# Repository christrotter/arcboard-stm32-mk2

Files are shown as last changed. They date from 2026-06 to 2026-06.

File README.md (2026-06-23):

# arcboard-stm32-mk2
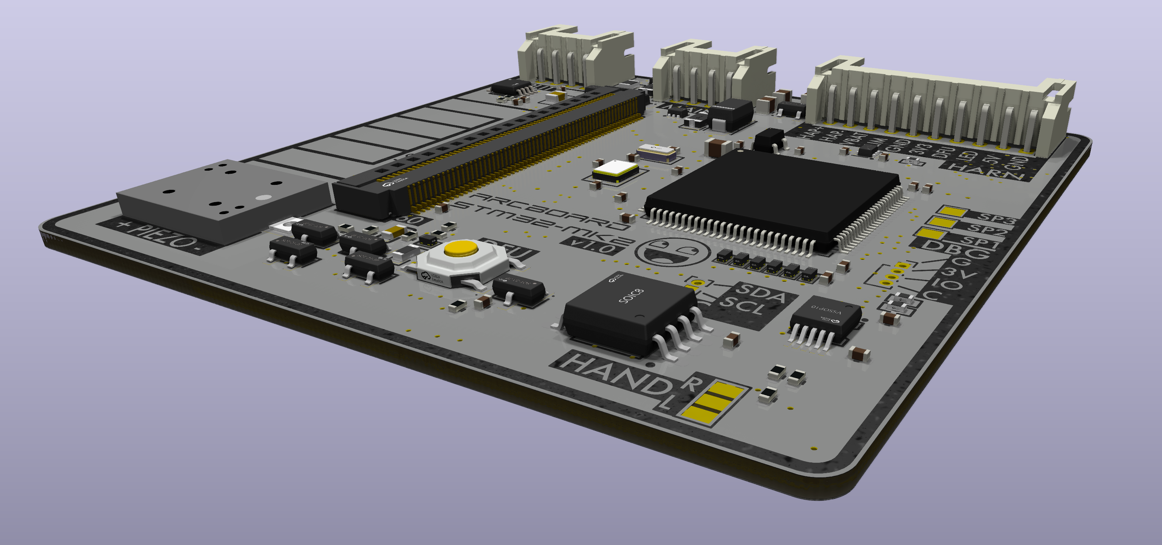
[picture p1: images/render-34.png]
Render

Next iteration of the [STM32F405 mainboard](https://github.com/christrotter/arcboard-stm32).

## Features
- STM32F407 w. 12mHz HSE crystal
- 60x60mm footprint
- **60-pin FFC connector** for [the bespoke FFC loom](https://github.com/christrotter/arcboard-mk22-ffc)
  - Connects: 3x encoders, 4x6 keywell & 5 thumb keys, dpad, 3x paddle buttons, LCD, indicator LED PCBs, PMW3360
- **onboard button** for reset(*momentary*) and boot(*hold*) (*remote output also*)
- 128mb external **flash** via SPI (16MB)
- DRV2605L **haptic** driver via I2C, with PWM trigger (LRA or ERM)
- PAM8302A 2.5w **amplifier & piezo** (*or outputs*)
- 32kHz LSE crystal & **VBAT** wiring (*via external 1.8-3.3v battery*)
- **Two-layer** PCB & PCBA design for more affordable manufacturing
- Both USB connections have **ESD & power protection**
- Designed for **remote-mount** USB ports and boot/reset button
- **Split hand** GPIO via solder jumper
- **VBUS detection** via GPIO
- RGB-5v and LCD-3.3v supplies through MOSFET w. GPIO triggers
- WS2812 signal **level-shifted** to 5v
- Optional outputs
  - I2C
  - Debug
  - Haptic
  - Amplifier out
  - Ground + RGB-5v + WS2812 chain (*continuing from main loom*) for adding more LEDs (*e.g. aesthetic, underglow, etc*)
  - **Limit switch** (pull-up) output

## Improvements
- 100-pin CPU package offers much more flexibility, more options when wiring up the board
- The only soldering required is for JST-PH connectors (*2.0mm pin spacing*)
- Smaller diode package and setup saves space, keeps us on two-layer
- Actually working DFU system this time (*bad LCD pcb caused problems*)
- Fixed a number of issues, including mysterious overheating caused by a poor quality Schottky diode (*and bad spec choice on my part*)
- Inkscape-designed back silkscreen

## QMK notes
- I'm using `ROW2COL` because the Cyboard pcb's are designed this way.

## PCB/PCBA cost
My costs for getting the board made and assembled by JLC, to give you an idea of what this would cost to have built for you.

| Item | Cost (CAD) |
|---|---:|
| Setup fee | $25.56 |
| Stencil | $8.21 |
| Components | $67.86 |
| Extended components fee | $53.55 |
| SMT Assembly | $3.75 |
| Packaging fee | $0.49 |
| Advanced Options | $0.82 |
| Confirm Parts Placement | $0.45 |

## Bill of Materials (BOM)

| Designator | Footprint | Quantity | Value | LCSC Part # |
|---|---|---:|---|---|
| C1, C10, C20, C23 | 0805 | 4 | 4.7uF | C1779 |
| C11, C12, C14, C17, C18, C19, C26, C28, C5, C7, C8, C9 | 0402 | 12 | 100nF | C1525 |
| C13, C15, C2, C24, C27, C4 | 0402 | 6 | 1uF | C52923 |
| C16, C21 | 0402 | 2 | 2.2uF | C12530 |
| C22 | C0603 | 1 | CL10A106MA8NRNC | C96446 |
| C25 | C0805 | 1 | GCM21BR70J106KE22L | C126230 |
| C29, C3, C30, C6 | 0402 | 4 | 12p | C1547 |
| D1 | SMA_L4.3-W2.6-LS5.2-RD | 1 | SS34 | C8678 |
| D10, D11, D2, D3, D6, D8, D9 | X1-DFN1006-2_L1.0-W0.6-RD | 7 | CDSQC4148-HF | C6341459 |
| D4 | SOD-123FL_L2.8-W1.8-LS3.7-BI | 1 | SMF5_0CA_C364279 | C364279 |
| D5, D7 | SOT-666-6_L1.6-W1.2-P0.50-LS1.6-BL | 2 | USBLC6-2P6_C2827693 | C2827693 |
| F2 | F1206 | 1 | 1206L150SLYR | C207037 |
| F3 | F1206 | 1 | MF-NSMF075-2 | C89653 |
| L1 | L0805 | 1 | MPZ2012S101AT000 | C15957 |
| LED-LVL1 | SOT-563_L1.6-W1.2-P0.50-LS1.6-BR | 1 | SN74LVC1T45DRL | C352970 |
| MOSFET1, MOSFET3, MOSFET4 | SOT-23_L2.9-W1.3-P1.90-LS2.4-BR | 3 | AO3401A | C15127 |
| R1 | 0402 | 1 | 0402WGF1004TCE | C26083 |
| R10 | 0402 | 1 | 5.1k | C25905 |
| R11, R12, R16, R17, R2, R3, R5 | 0402 | 7 | 10k | C25744 |
| R4, R7, R8 | R0402 | 3 | 0402WGF4701TCE | C25900 |
| R14 | 0402 | 1 | 0402WGF1000TCE | C25076 |
| R15 | 0402 | 1 | 0402WGF1001TCE | C11702 |
| R6 | R0603 | 1 | 0603WAF3303T5E | C23137 |
| R9 | 0402 | 1 | 0402WGF1003TCE | C25741 |
| U1 | SOT-23-5 | 1 | XC6210B332MR-G | C82942 |
| U10, U9 | SOT-23-3_L2.9-W1.3-P1.90-LS2.4-BR | 2 | MMUN2233LT1G | C86932 |
| U13, U4 | SOT-23-3_L2.9-W1.3-P1.90-LS2.4-BR | 2 | 2N7002 | C8545 |
| U14 | SOIC-8_L5.3-W5.3-P1.27-LS8.0-BL | 1 | W25Q128JVSIQTR | C97521 |
| U15 | SW-SMD_4P-L5.1-W5.1-P3.70-LS6.5-TL_H1.5 | 1 | TS-1187A-B-A-B | C318884 |
| U2 | LQFP-100_14x14mm_P0.5mm | 1 | STM32F407VGTx | C12345 |
| U3 | FPC-SMD_FH52-60S-0.5SH | 1 | FH52-60S-0_5SH | C224193 |
| U5 | VSSOP-10_L3.0-W3.0-P0.50-LS4.9-BL | 1 | DRV2605LDGSR | C527464 |
| U6 | MSOP-8_L3.0-W3.0-P0.65-LS5.0-BL | 1 | PAM8302AASCR | C113367 |
| U8 | OSC-SMD_L3.2-W1.5 | 1 | SC-32S32_768kHz20PPM7pF | C97604 |
| Y1 | CRYSTAL-SMD_4P-L3.2-W2.5-BL-1 | 1 | Crystal_GND24 | C9002 |

Total line items: 35  
Total component quantity: 77

## Renders

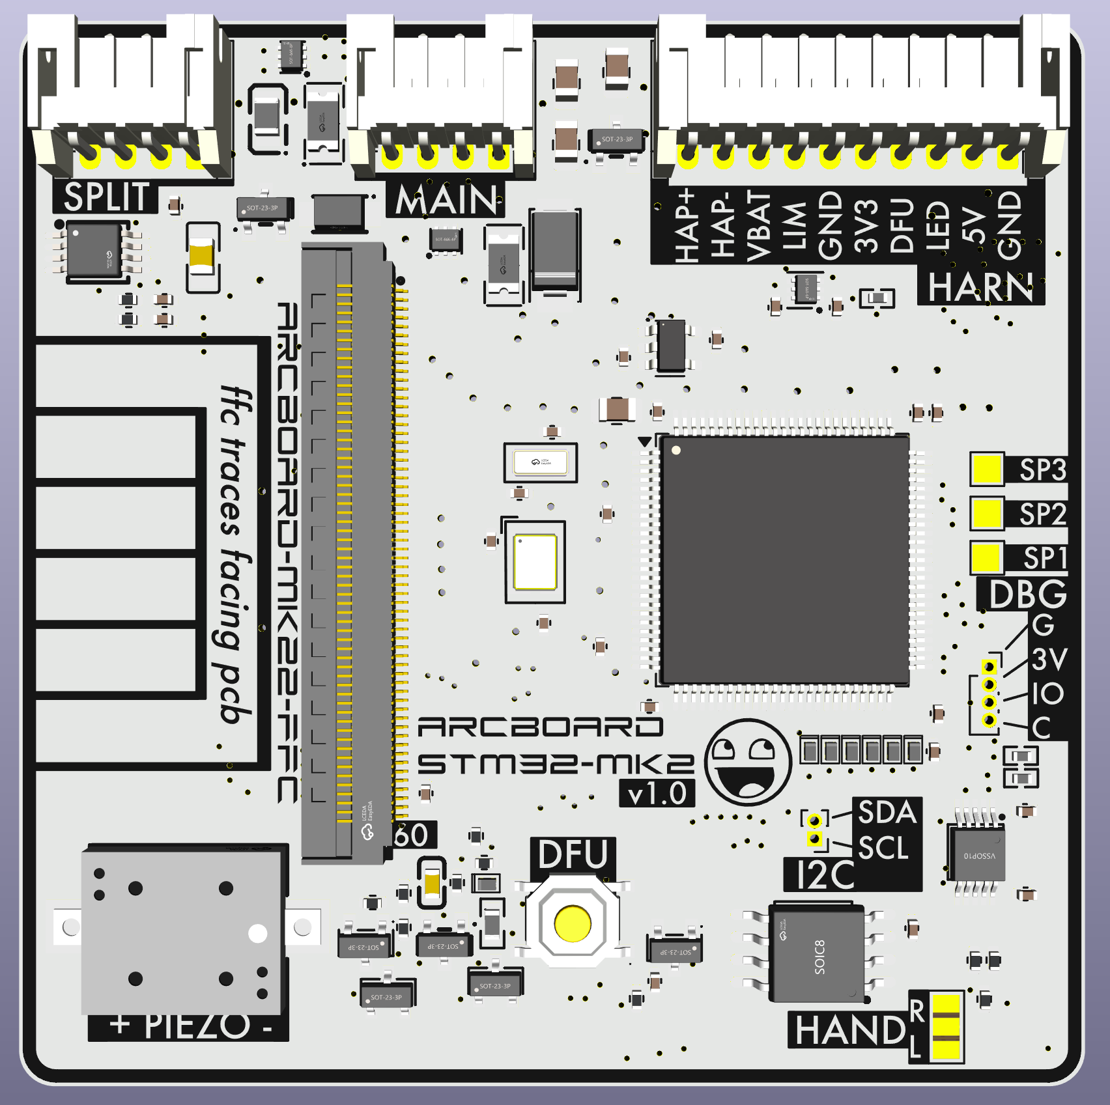
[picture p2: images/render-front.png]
Render


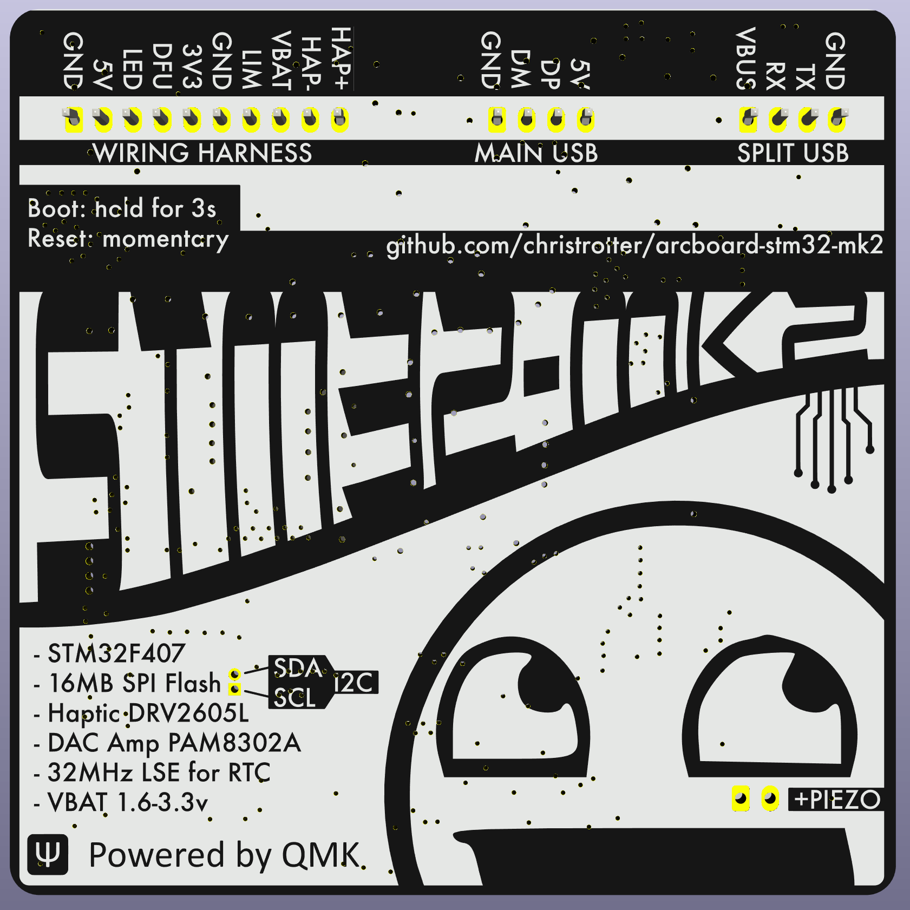
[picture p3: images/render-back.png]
Render


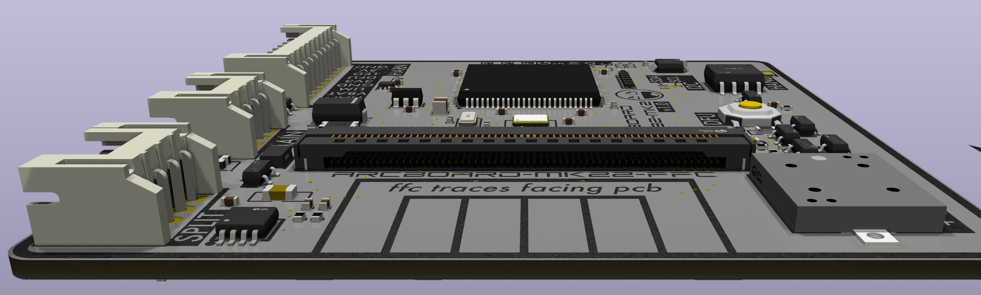
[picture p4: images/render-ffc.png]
Render


## PCB layout
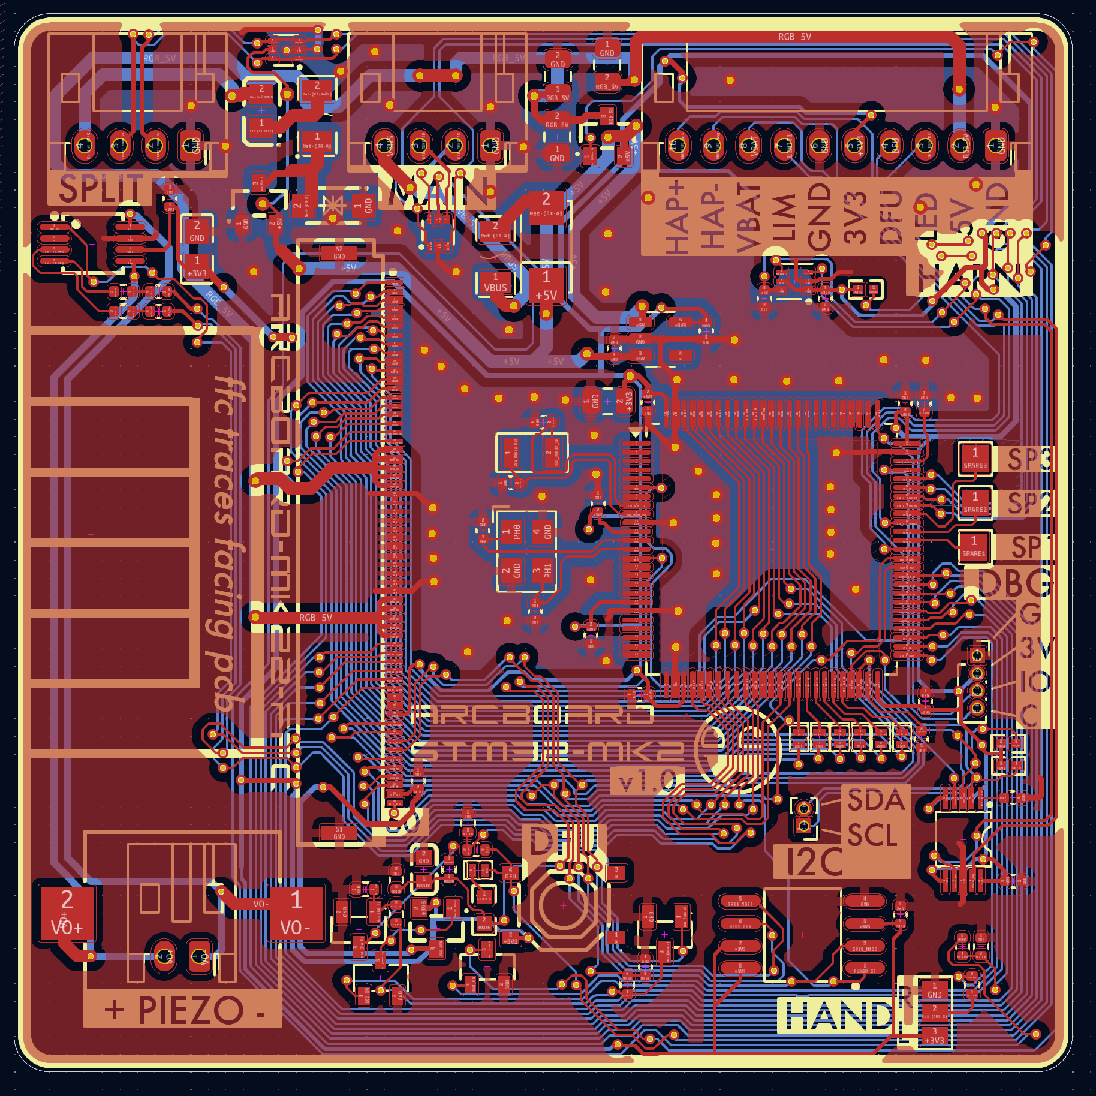
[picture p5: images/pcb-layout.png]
PCB Layout


## Schematic
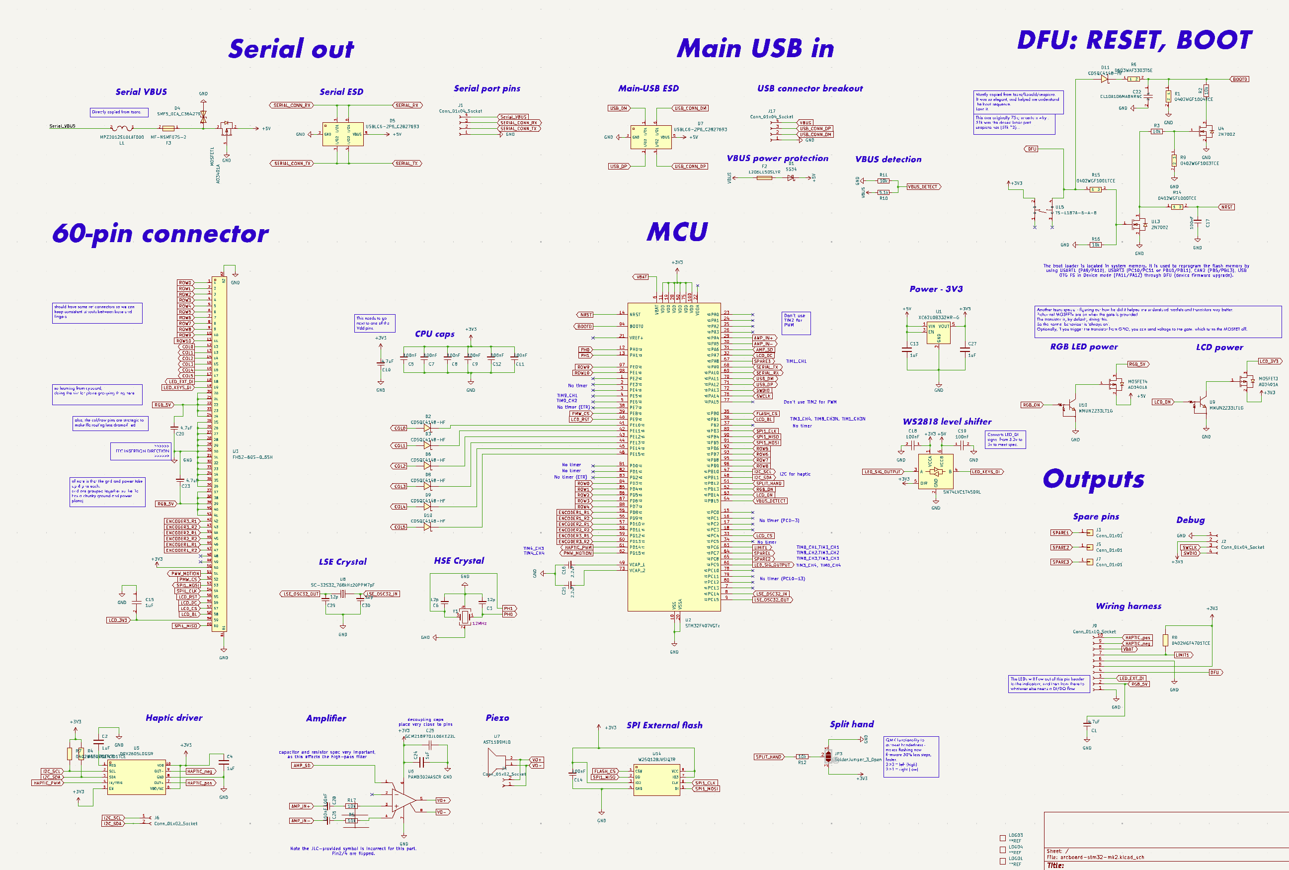
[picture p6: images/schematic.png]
Schematic


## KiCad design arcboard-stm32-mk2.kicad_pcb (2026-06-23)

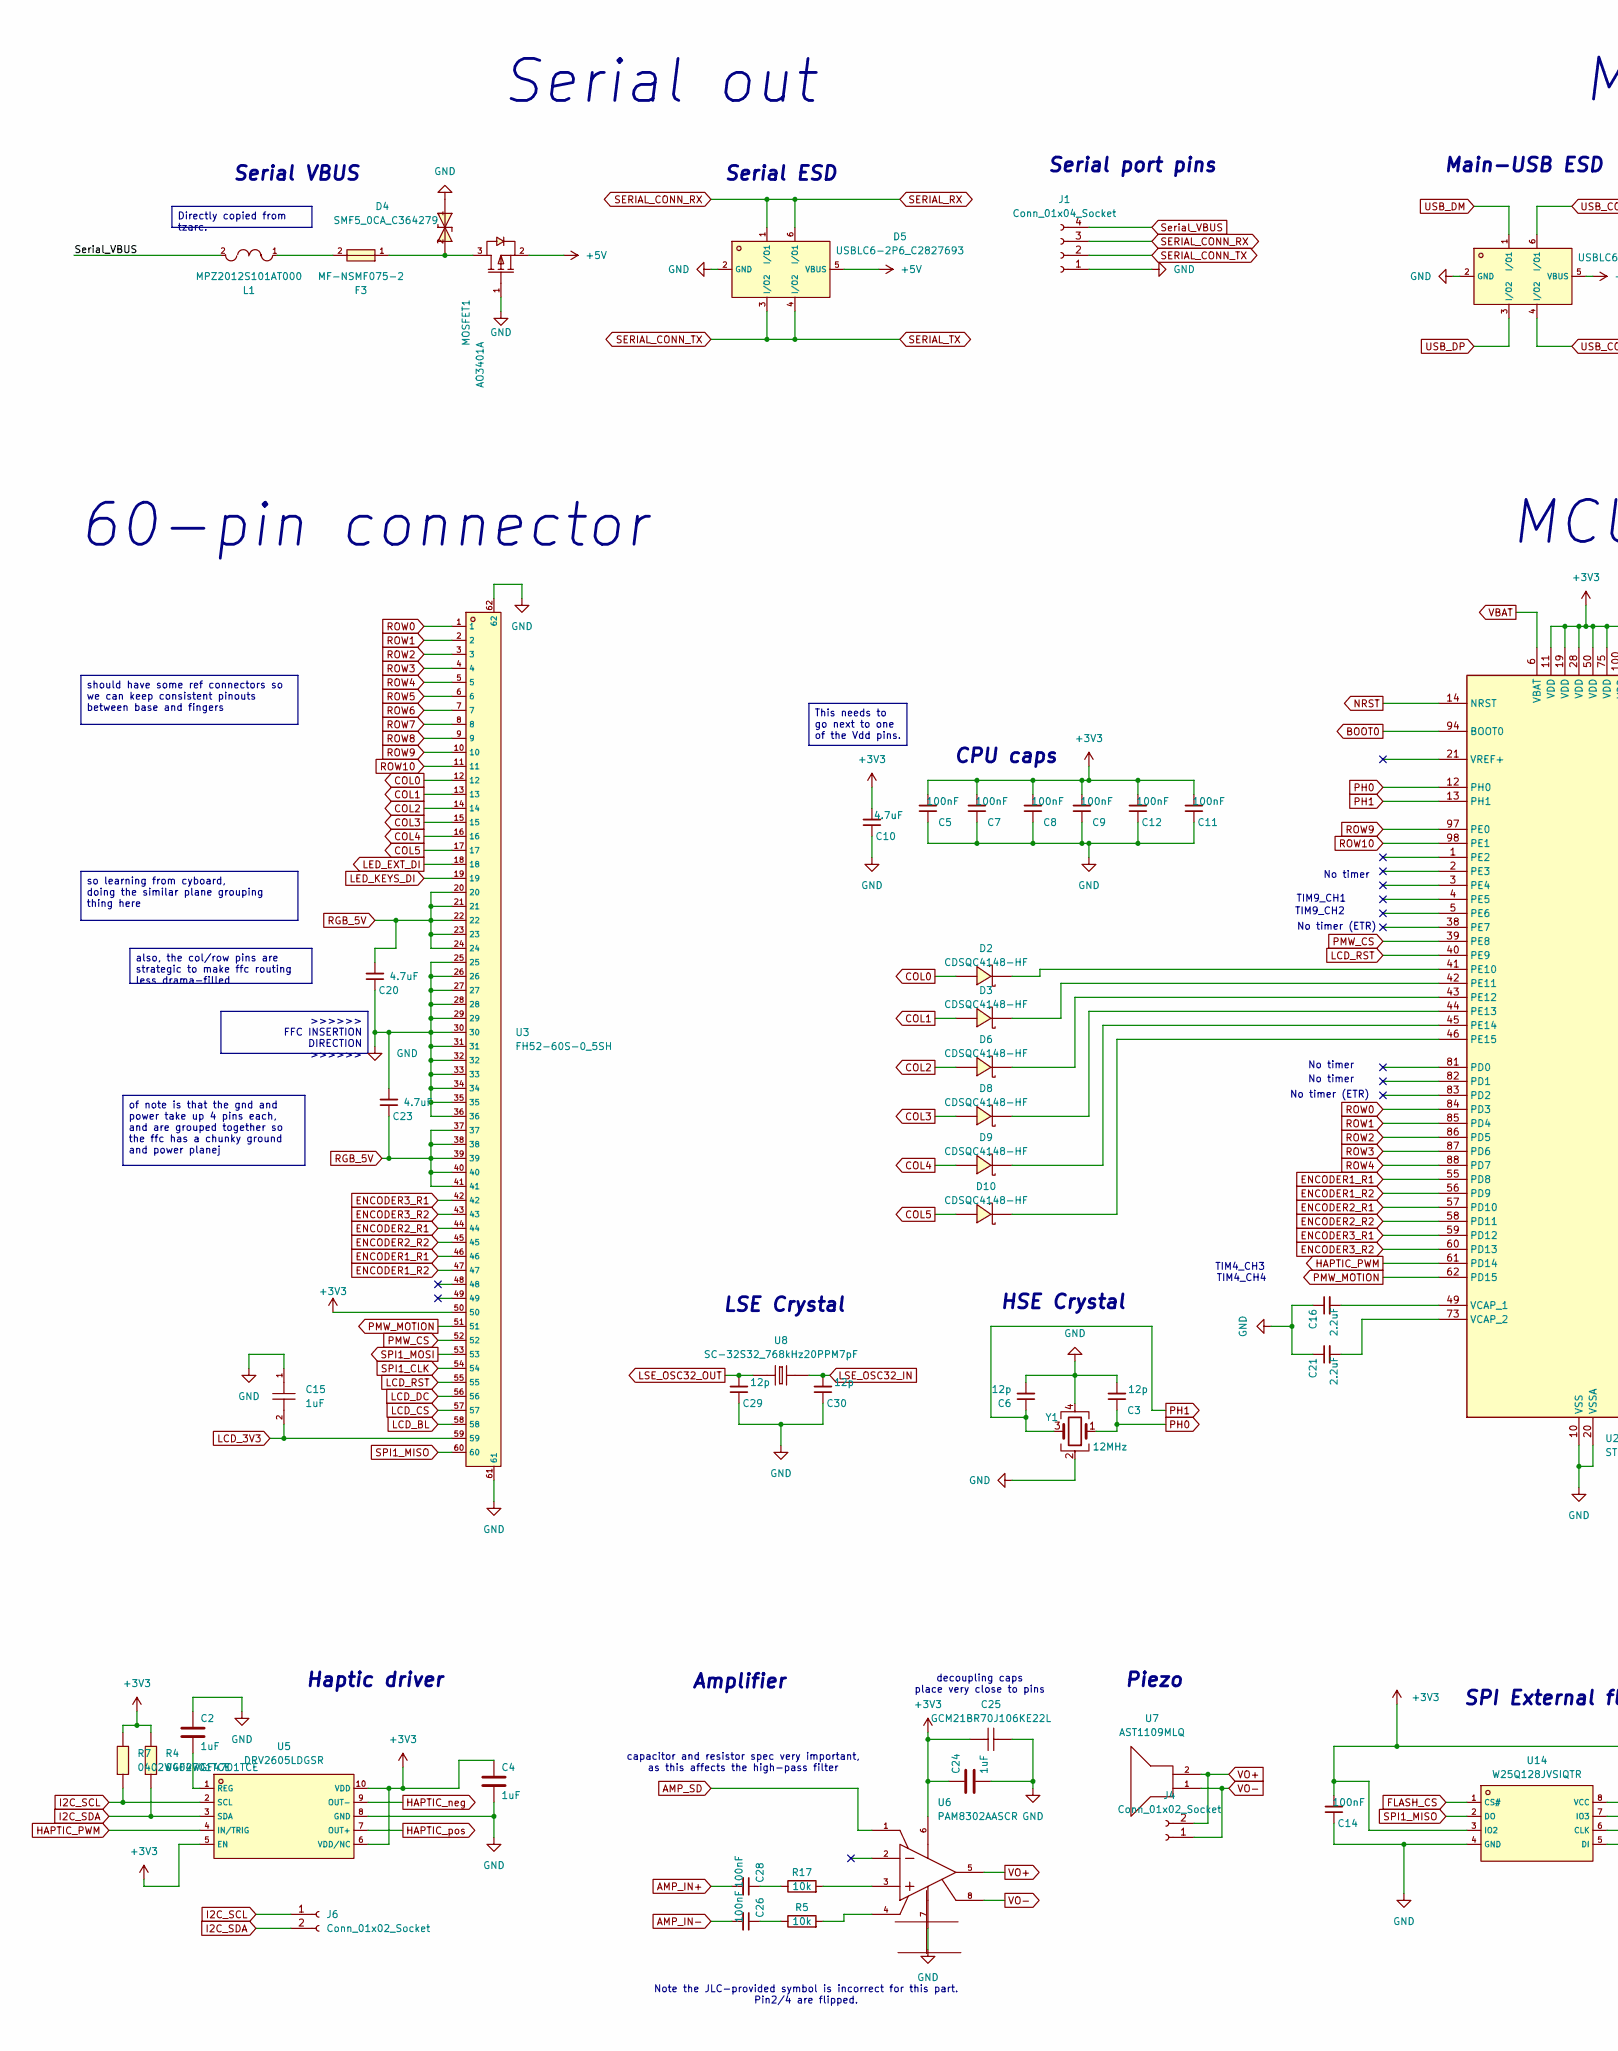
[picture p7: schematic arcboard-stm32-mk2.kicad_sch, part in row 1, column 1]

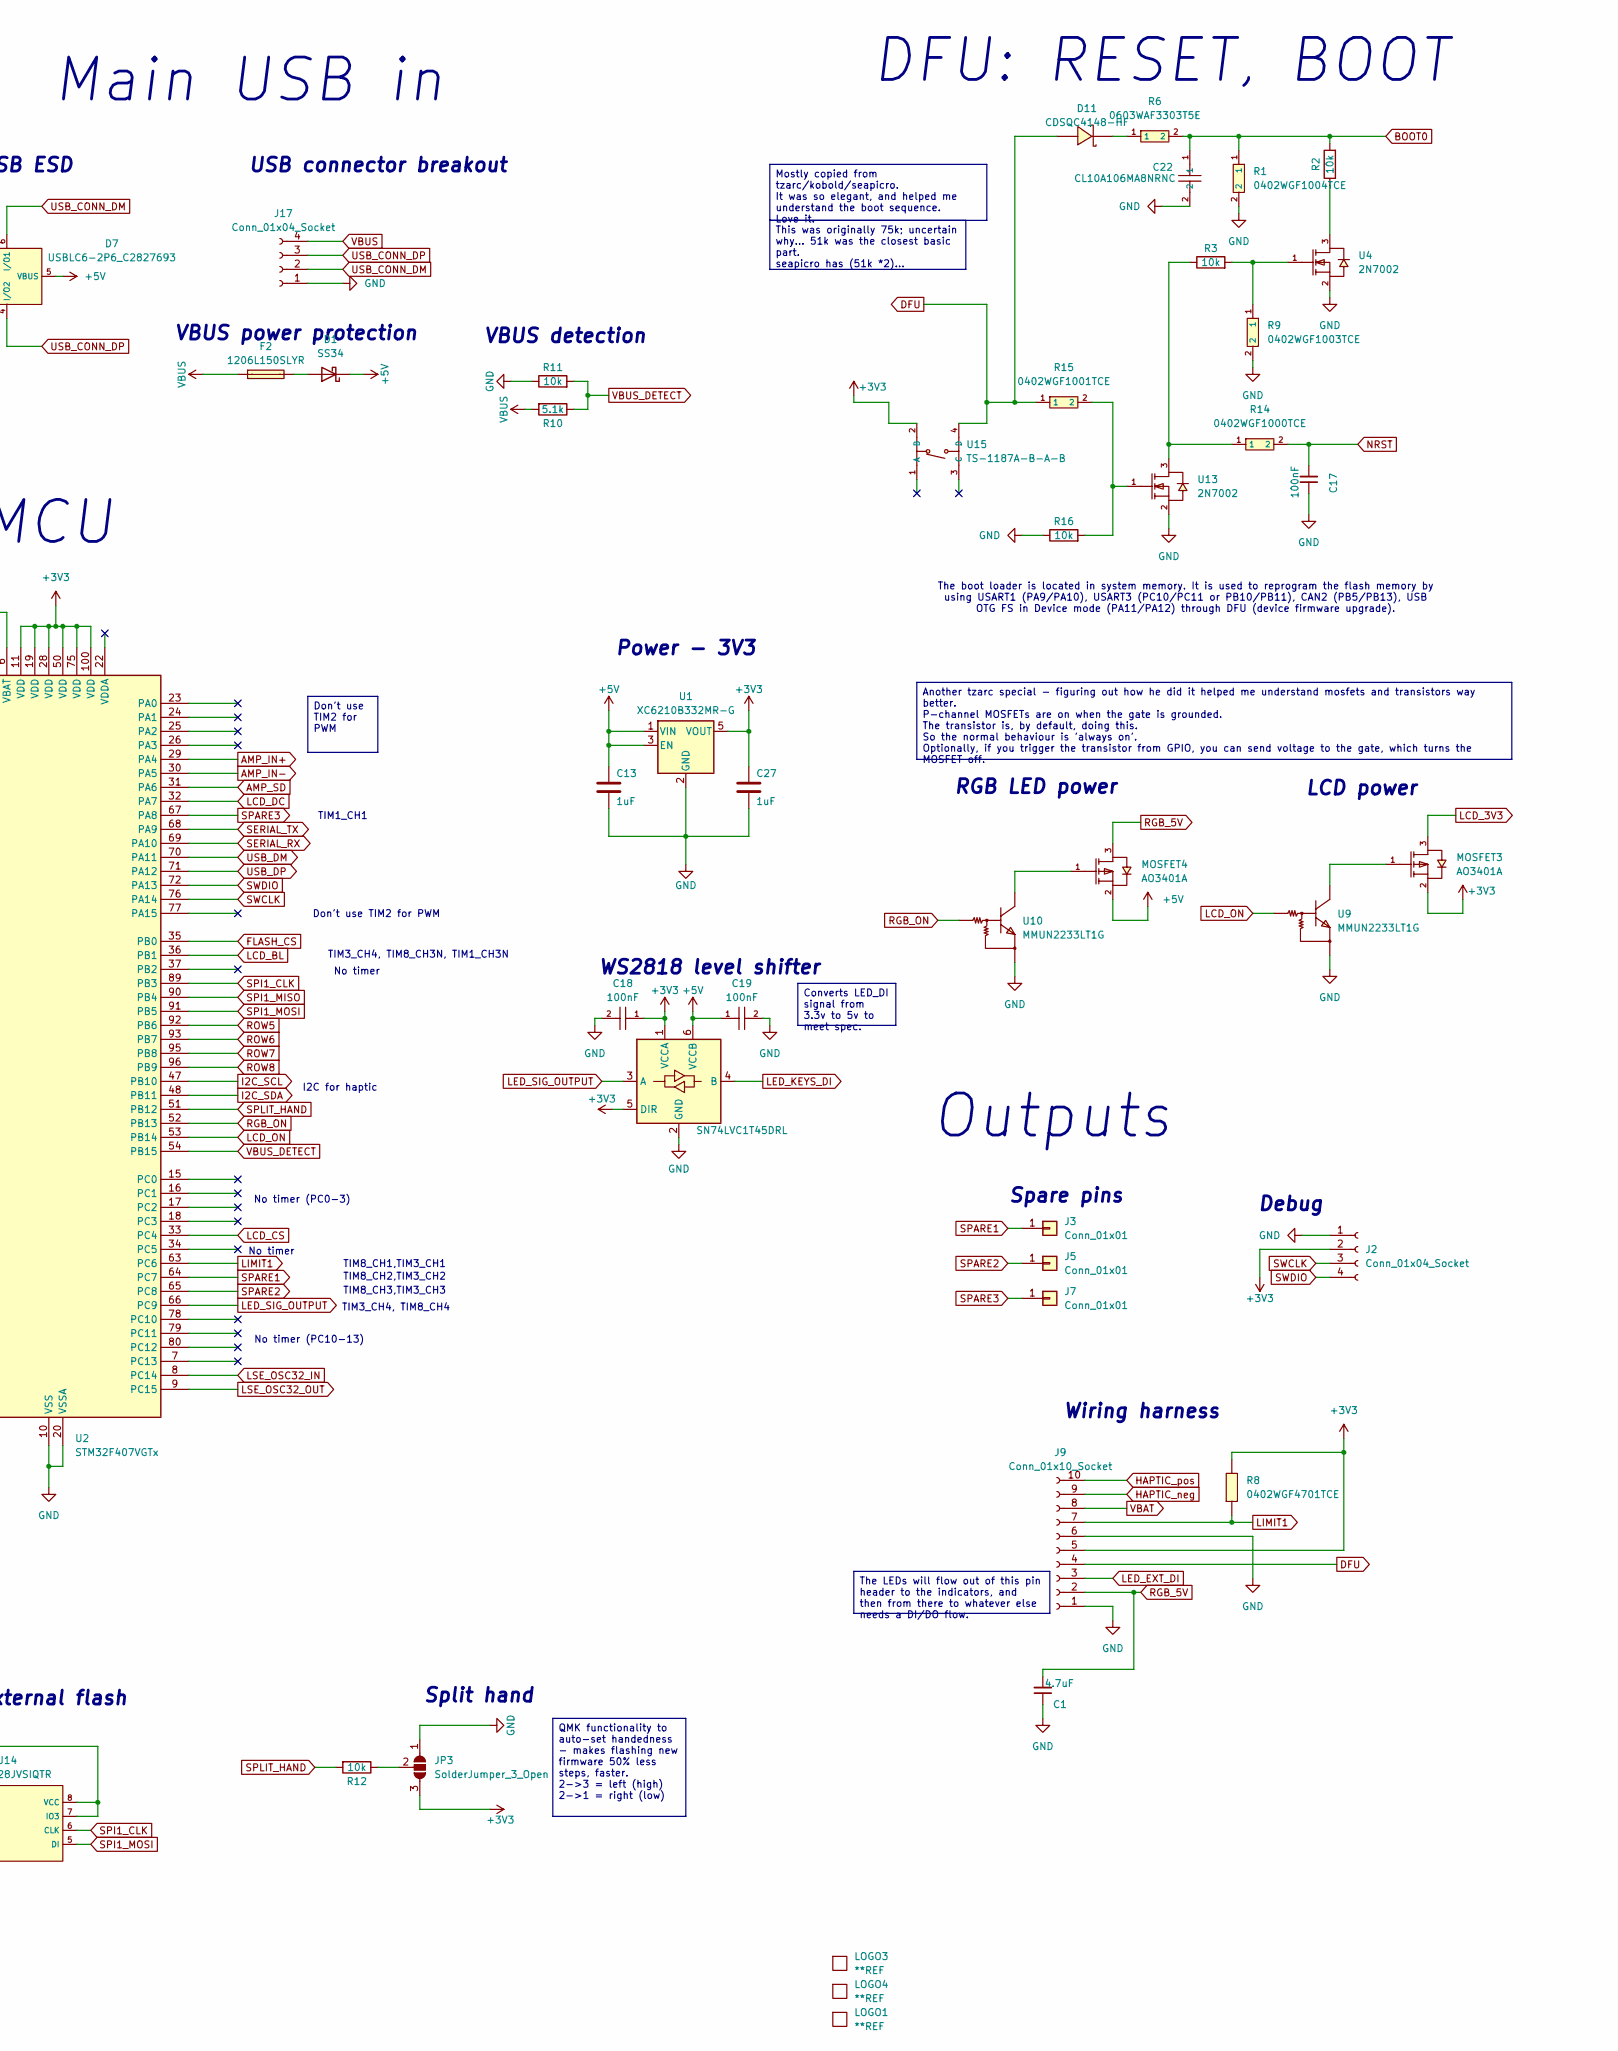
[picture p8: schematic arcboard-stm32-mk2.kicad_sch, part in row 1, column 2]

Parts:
C1, C10, C20, C23: 4.7uF; C_0805_2012Metric; LCSC C1779
C2, C4, C13, C15, C24, C27: 1uF; C_0402_1005Metric; LCSC C52923
C3, C6, C29, C30: 12p; C_0402_1005Metric; LCSC C1547
C5, C7, C8, C9, C11, C12, C14, C17, C18, C19, C26, C28: 100nF; C_0402_1005Metric; LCSC C1525
C16, C21: 2.2uF; C_0402_1005Metric; LCSC C12530
C22: CL10A106MA8NRNC; C0603; LCSC C96446
C25: GCM21BR70J106KE22L; C0805; LCSC C126230
D1: SS34; SMA_L4.3-W2.6-LS5.2-RD; LCSC C8678
D2, D3, D6, D8, D9, D10, D11: CDSQC4148-HF; X1-DFN1006-2_L1.0-W0.6-RD; LCSC C6341459
D4: SMF5_0CA_C364279; SOD-123FL_L2.8-W1.8-LS3.7-BI; LCSC C364279
D5, D7: USBLC6-2P6_C2827693; SOT-666-6_L1.6-W1.2-P0.50-LS1.6-BL; LCSC C2827693
F2: 1206L150SLYR; F1206; LCSC C207037
F3: MF-NSMF075-2; F1206; LCSC C89653
J1, J17: Conn_01x04_Socket; JST_PH_S4B-PH-K_1x04_P2.00mm_Horizontal
J2: Conn_01x04_Socket; PinSocket_1x04_P1.00mm_Vertical
J3, J5, J7: Conn_01x01; TestPoint_Pad_1.5x1.5mm
J4: Conn_01x02_Socket; JST_PH_S2B-PH-K_1x02_P2.00mm_Horizontal
J6: Conn_01x02_Socket; PinHeader_1x02_P1.00mm_Vertical
J9: Conn_01x10_Socket; JST_PH_S10B-PH-K_1x10_P2.00mm_Horizontal
JP3: SolderJumper_3_Open; SolderJumper-3_P1.3mm_Open_Pad1.0x1.5mm
L1: MPZ2012S101AT000; L0805; LCSC C15957
LED-LVL1: SN74LVC1T45DRL; SOT-563_L1.6-W1.2-P0.50-LS1.6-BR; MPN SN74LVC1T45DRLR; JLC Basic N
LOGO1: **REF; awesome-logo
LOGO3: **REF; cyboard-logo-10mm
LOGO4: **REF; qmk-lite
MOSFET1, MOSFET3, MOSFET4: AO3401A; SOT-23_L2.9-W1.3-P1.90-LS2.4-BR; LCSC C15127
R1: 0402WGF1004TCE; R_0402_1005Metric; LCSC C26083
R2, R3, R5, R11, R12, R16, R17: 10k; R_0402_1005Metric; LCSC C25744
R4, R7, R8: 0402WGF4701TCE; R0402; LCSC C25900
R6: 0603WAF3303T5E; R0603; LCSC C23137
R9: 0402WGF1003TCE; R_0402_1005Metric; LCSC C25741
R10: 5.1k; R_0402_1005Metric; LCSC C25905
R14: 0402WGF1000TCE; R_0402_1005Metric; LCSC C25076
R15: 0402WGF1001TCE; R_0402_1005Metric; LCSC C11702
U1: XC6210B332MR-G; SOT-23-5; LCSC C82942
U2: STM32F407VGTx; LQFP-100_14x14mm_P0.5mm; LCSC C12345
U3: FH52-60S-0_5SH; FPC-SMD_FH52-60S-0.5SH; LCSC C224193
U4, U13: 2N7002; SOT-23-3_L2.9-W1.3-P1.90-LS2.4-BR; LCSC C8545
U5: DRV2605LDGSR; VSSOP-10_L3.0-W3.0-P0.50-LS4.9-BL; LCSC C527464
U6: PAM8302AASCR; MSOP-8_L3.0-W3.0-P0.65-LS5.0-BL; LCSC C113367
U7: AST1109MLQ; BUZ-SMD_L11.0-W9.0; LCSC C9900020429
U8: SC-32S32_768kHz20PPM7pF; OSC-SMD_L3.2-W1.5; LCSC C97604
U9, U10: MMUN2233LT1G; SOT-23-3_L2.9-W1.3-P1.90-LS2.4-BR; LCSC C86932
U14: W25Q128JVSIQTR; SOIC-8_L5.3-W5.3-P1.27-LS8.0-BL; LCSC C97521
U15: TS-1187A-B-A-B; SW-SMD_4P-L5.1-W5.1-P3.70-LS6.5-TL_H1.5; LCSC C318884
Y1: Crystal_GND24; CRYSTAL-SMD_4P-L3.2-W2.5-BL-1; LCSC C9002

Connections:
+3V3: C4.1, C5.2, C7.2, C8.2, C9.2, C10.2, C11.2, C12.2, C14.2, C18.1, C24.1, C25.1, C27.1, J2.2, J9.5, JP3.3 (B), LED-LVL1.1 (VCCA), LED-LVL1.5 (DIR), MOSFET3.2 (S), R4.2, R7.2, R8.2, U1.5 (VOUT), U2.11 (VDD), U2.19 (VDD), U2.28 (VDD), U2.50 (VDD), U2.75 (VDD), U2.100 (VDD), U3.50, U5.5 (EN), U5.6 (VDD/NC), U5.10 (VDD), U6.6 (VDD), U14.3 (IO2), U14.7 (IO3), U14.8 (VCC), U15.2 (B)
+5V: C13.1, C19.1, D1.1 (K), D5.5 (VBUS), D7.5 (VBUS), LED-LVL1.6 (VCCB), MOSFET1.2 (S), MOSFET4.2 (S), U1.1 (VIN), U1.3 (EN)
AMP_IN+: C28.2, U2.29 (PA4)
AMP_IN-: C26.2, U2.30 (PA5)
AMP_SD: U2.31 (PA6), U6.1 (SD#)
BOOT0: C22.1, R1.1, R2.2, R6.2, U2.94 (BOOT0)
COL0: D2.2 (A), U3.12
COL1: D3.2 (A), U3.13
COL2: D6.2 (A), U3.14
COL3: D8.2 (A), U3.15
COL4: D9.2 (A), U3.16
COL5: D10.2 (A), U3.17
DFU: D11.2 (A), J9.4, R15.1, U15.4 (D)
ENCODER1_R1: U2.55 (PD8), U3.46
ENCODER1_R2: U2.56 (PD9), U3.47
ENCODER2_R1: U2.57 (PD10), U3.44
ENCODER2_R2: U2.58 (PD11), U3.45
ENCODER3_R1: U2.59 (PD12), U3.42
ENCODER3_R2: U2.60 (PD13), U3.43
FLASH_CS: U2.35 (PB0), U14.1 (CS#)
GND: C1.1, C2.1, C3.2, C4.2, C5.1, C6.2, C7.1, C8.1, C9.1, C10.1, C11.1, C12.1, C13.2, C14.1, C15.1, C16.1, C17.1, C18.2, C19.2, C20.1, C21.1, C22.2, C23.2, C24.2, C25.2, C27.2, C29.1, C30.1, D4.1 (K), D5.2 (GND), D7.2 (GND), J1.1, J2.1, J9.1, J9.6, J17.1, JP3.1 (A), LED-LVL1.2 (GND), MOSFET1.1 (G), R1.2, R9.2, R11.1, R16.1, U1.2 (GND), U2.10 (VSS), U2.20 (VSSA), U2.27 (VSS), U2.74 (VSS), U2.99 (VSS), U3.25, U3.26, U3.27, U3.28, U3.29, U3.30, U3.31, U3.32, U3.33, U3.34, U3.35, U3.36, U3.61, U3.62, U4.2 (S), U5.8 (GND), U6.7 (GND), U9.2 (E), U10.2 (E), U13.2 (S), U14.4 (GND), Y1.2, Y1.4
HAPTIC_PWM: U2.61 (PD14), U5.4 (IN/TRIG)
HAPTIC_neg: J9.9, U5.9 (OUT-)
HAPTIC_pos: J9.10, U5.7 (OUT+)
I2C_SCL: J6.1, R7.1, U2.47 (PB10), U5.2 (SCL)
I2C_SDA: J6.2, R4.1, U2.48 (PB11), U5.3 (SDA)
LCD_3V3: C15.2, MOSFET3.3 (D), U3.59
LCD_BL: U2.36 (PB1), U3.58
LCD_CS: U2.33 (PC4), U3.57
LCD_DC: U2.32 (PA7), U3.56
LCD_ON: U2.53 (PB14), U9.1 (B)
LCD_RST: U2.40 (PE9), U3.55
LED_EXT_DI: J9.3, U3.18
LED_KEYS_DI: LED-LVL1.4 (B), U3.19
LED_SIG_OUTPUT: LED-LVL1.3 (A), U2.66 (PC9)
LIMIT1: J9.7, R8.1, U2.63 (PC6)
LSE_OSC32_IN: C30.2, U2.8 (PC14), U8.2
LSE_OSC32_OUT: C29.2, U2.9 (PC15), U8.1
NRST: C17.2, R14.2, U2.14 (NRST)
unnamed: C26.1, R5.1
unnamed: C28.1, R17.1
unnamed: D1.2 (A), F2.2
unnamed: D2.1 (K), U2.41 (PE10)
unnamed: D3.1 (K), U2.42 (PE11)
unnamed: D4.2 (A), F3.1, MOSFET1.3 (D)
unnamed: D6.1 (K), U2.43 (PE12)
unnamed: D8.1 (K), U2.44 (PE13)
unnamed: D9.1 (K), U2.45 (PE14)
unnamed: D10.1 (K), U2.46 (PE15)
unnamed: D11.1 (K), R6.1
unnamed: F3.2, L1.1
unnamed: JP3.2 (C), R12.1
unnamed: MOSFET3.1 (G), U9.3 (C)
unnamed: MOSFET4.1 (G), U10.3 (C)
unnamed: C16.2, U2.49 (VCAP_1)
unnamed: C21.2, U2.73 (VCAP_2)
unnamed: R2.1, U4.3 (D)
unnamed: R3.2, R9.1, U4.1 (G)
unnamed: C2.2, U5.1 (REG)
unnamed: R17.2, U6.3 (IN+)
unnamed: R5.2, U6.4 (IN-)
unnamed: R3.1, R14.1, U13.3 (D)
unnamed: R15.2, R16.2, U13.1 (G)
PH0: C3.1, U2.12 (PH0), Y1.1
PH1: C6.1, U2.13 (PH1), Y1.3
PMW_CS: U2.39 (PE8), U3.52
PMW_MOTION: U2.62 (PD15), U3.51
RGB_5V: C1.2, C20.2, C23.1, J9.2, MOSFET4.3 (D), U3.20, U3.21, U3.22, U3.23, U3.24, U3.37, U3.38, U3.39, U3.40, U3.41
RGB_ON: U2.52 (PB13), U10.1 (B)
ROW0: U2.84 (PD3), U3.1
ROW1: U2.85 (PD4), U3.2
ROW2: U2.86 (PD5), U3.3
ROW3: U2.87 (PD6), U3.4
ROW4: U2.88 (PD7), U3.5
ROW5: U2.92 (PB6), U3.6
ROW6: U2.93 (PB7), U3.7
ROW7: U2.95 (PB8), U3.8
ROW8: U2.96 (PB9), U3.9
ROW9: U2.97 (PE0), U3.10
ROW10: U2.98 (PE1), U3.11
SERIAL_CONN_RX: D5.1 (I/O1), D5.6 (I/O1), J1.3, U2.69 (PA10)
SERIAL_CONN_TX: D5.3 (I/O2), D5.4 (I/O2), J1.2, U2.68 (PA9)
SPARE1: J3.1, U2.64 (PC7)
SPARE2: J5.1, U2.65 (PC8)
SPARE3: J7.1, U2.67 (PA8)
SPI1_CLK: U2.89 (PB3), U3.54, U14.6 (CLK)
SPI1_MISO: U2.90 (PB4), U3.60, U14.2 (DO)
SPI1_MOSI: U2.91 (PB5), U3.53, U14.5 (DI)
SPLIT_HAND: R12.2, U2.51 (PB12)
SWCLK: J2.3, U2.76 (PA14)
SWDIO: J2.4, U2.72 (PA13)
Serial_VBUS: J1.4, L1.2
USB_CONN_DM: D7.6 (I/O1), J17.2
USB_CONN_DP: D7.4 (I/O2), J17.3
USB_DM: D7.1 (I/O1), U2.70 (PA11)
USB_DP: D7.3 (I/O2), U2.71 (PA12)
VBAT: J9.8, U2.6 (VBAT)
VBUS: F2.1, J17.4, R10.2
VBUS_DETECT: R10.1, R11.2, U2.54 (PB15)
VO+: J4.2, U6.5 (VO+), U7.2
VO-: J4.1, U6.8 (VO-), U7.1

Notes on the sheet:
No timer (PC10-13)
Amplifier
LSE Crystal
TIM9_CH2
DFU: RESET, BOOT
TIM8_CH3,TIM3_CH3
Serial VBUS
I2C for haptic
No timer
TIM3_CH4, TIM8_CH4
TIM8_CH2,TIM3_CH2
Serial port pins
Outputs
USB connector breakout
Don't use TIM2 for PWM
No timer (ETR)
TIM1_CH1
decoupling caps place very close to pins
HSE Crystal
Main USB in
TIM8_CH1,TIM3_CH1
CPU caps
No timer (PC0-3)
VBUS detection
RGB LED power
Wiring harness
SPI External flash
Piezo
Power - 3V3
TIM9_CH1
TIM3_CH4, TIM8_CH3N, TIM1_CH3N
Note the JLC-provided symbol is incorrect for this part. Pin2/4 are flipped.
LCD power
Spare pins
60-pin connector
WS2818 level shifter
Split hand
Haptic driver
capacitor and resistor spec very important, as this affects the high-pass filter
TIM4_CH4

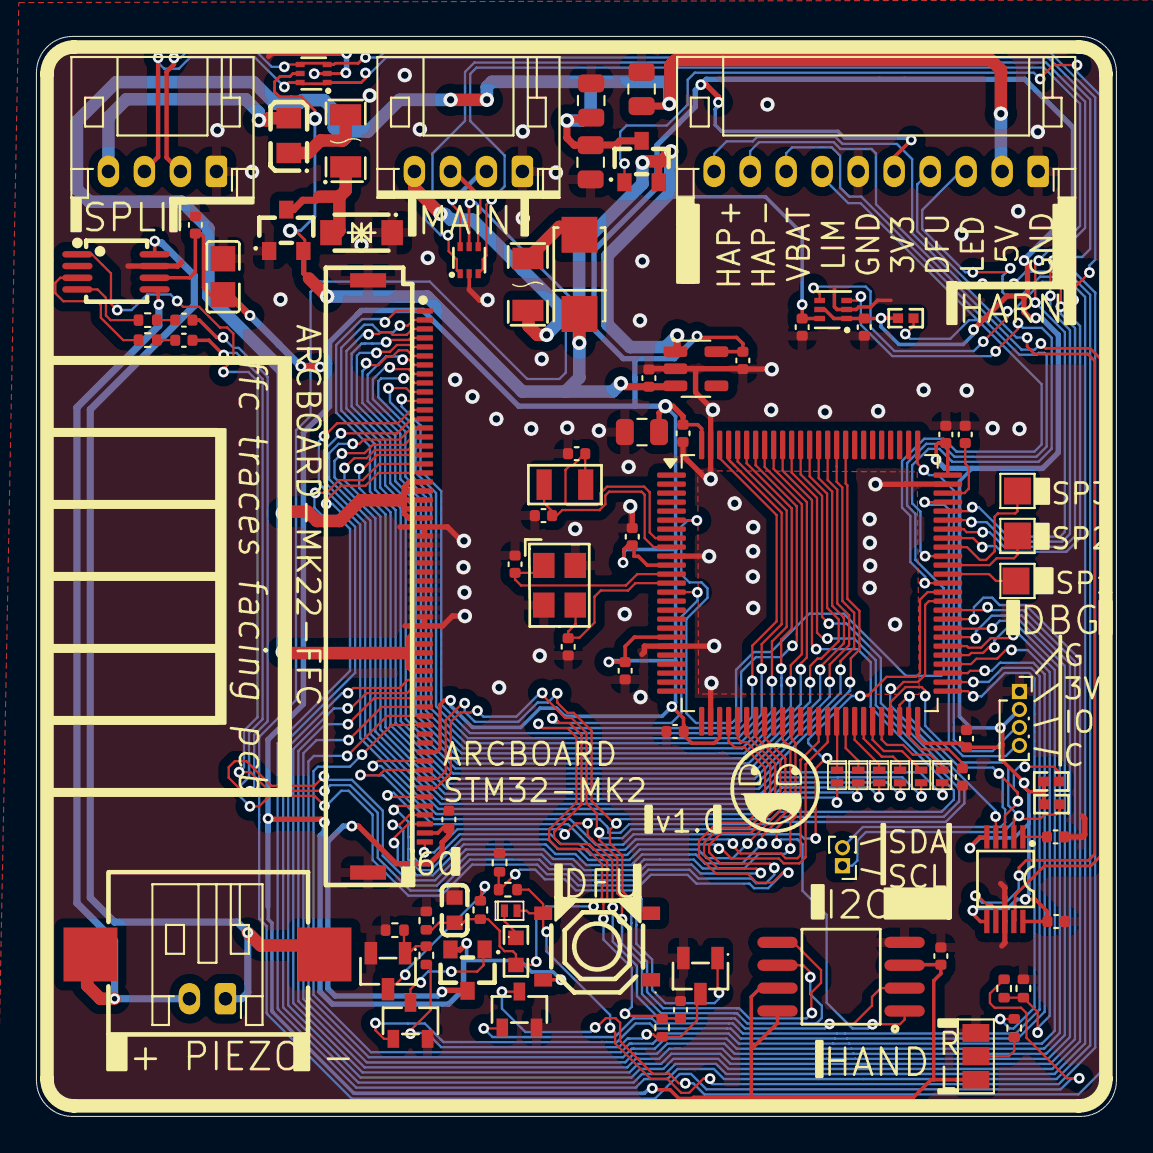
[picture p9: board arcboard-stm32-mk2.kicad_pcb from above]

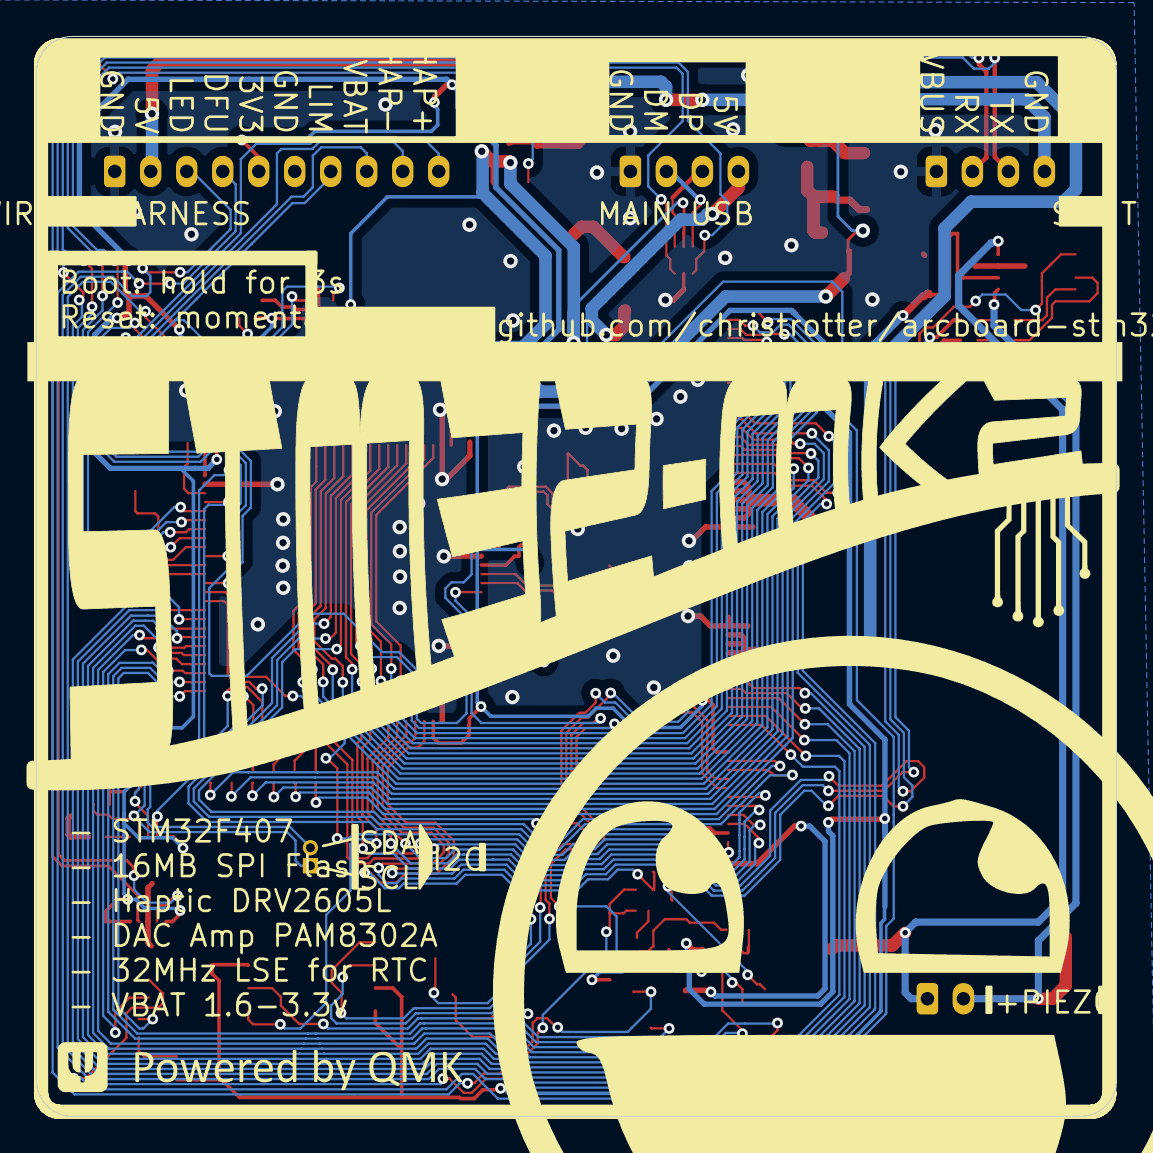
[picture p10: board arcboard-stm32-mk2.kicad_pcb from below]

Board: 2 copper layers, 60.0 x 60.0 mm, 91 parts (2 on the bottom side), 101 nets.

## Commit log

2026-05-31 adding first draft kicad files
    [arcboard-stm32-mk2.kicad_pcb, arcboard-stm32-mk2.kicad_sch]
2026-06-01 starting readme, added haptic
    [arcboard-stm32-mk2.kicad_pcb, arcboard-stm32-mk2.kicad_sch]
2026-06-01 finishing haptic bits
    [arcboard-stm32-mk2.kicad_pcb, arcboard-stm32-mk2.kicad_sch]
2026-06-01 adding dac amp
    [arcboard-stm32-mk2.kicad_pcb, arcboard-stm32-mk2.kicad_sch]
2026-06-02 adding piezo that does not fit
    [arcboard-stm32-mk2.kicad_pcb, arcboard-stm32-mk2.kicad_sch]
2026-06-02 re-organized the bottom section to fit a piezo
    [arcboard-stm32-mk2.kicad_pcb, arcboard-stm32-mk2.kicad_sch]
2026-06-03 silkscreen work, adding lse crystal and vbat hookup
    [arcboard-stm32-mk2.kicad_pcb, arcboard-stm32-mk2.kicad_sch]
2026-06-04 fixing issues brought up by drashna, adding timer notation to schematic
    [arcboard-stm32-mk2.kicad_pcb, arcboard-stm32-mk2.kicad_sch]
2026-06-04 improving top silkscreen
    [arcboard-stm32-mk2.kicad_pcb]
2026-06-04 top silkscreen good enough for now
    [arcboard-stm32-mk2.kicad_pcb]
2026-06-05 silkscreen mostly done, fixed some DRC issues
    [arcboard-stm32-mk2.kicad_pcb]
2026-06-05 tidying up ground planes, traces
    [arcboard-stm32-mk2.kicad_pcb]
2026-06-05 fixing haptic driver missing another vdd, more
    [arcboard-stm32-mk2.kicad_pcb, arcboard-stm32-mk2.kicad_sch]
2026-06-05 moving i2c breakout to not interfere with rear silkscreen, moving piezo b.silk label
    [arcboard-stm32-mk2.kicad_pcb]
2026-06-06 refactoring rgb-lcd power to match tzarc, old way was fundamentally broken
    [arcboard-stm32-mk2.kicad_pcb, arcboard-stm32-mk2.kicad_sch]
2026-06-06 silkscreen refactoring and moving bits around
    [arcboard-stm32-mk2.kicad_pcb, arcboard-stm32-mk2.kicad_sch]
2026-06-06 improved polyfuse part, fixing critical amplifier symbol mistake, other re-ordering
    [arcboard-stm32-mk2.kicad_pcb, arcboard-stm32-mk2.kicad_sch]
2026-06-06 almost ready for ordering
    [arcboard-stm32-mk2.kicad_sch]
2026-06-09 fixing i2c resistors, prepping for 10pin
    [arcboard-stm32-mk2.kicad_pcb, arcboard-stm32-mk2.kicad_sch]
2026-06-23 bunch o updates
    [arcboard-stm32-mk2.kicad_pcb, arcboard-stm32-mk2.kicad_sch]
